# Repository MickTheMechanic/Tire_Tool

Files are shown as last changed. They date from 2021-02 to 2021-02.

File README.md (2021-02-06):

# Tire Tool
## An open-source datalogging tire pyrometer with built in thermal camera and tire pressure gauge
<br />This work is licensed under a <a rel="license" href="http://creativecommons.org/licenses/by-nc/4.0/">Creative Commons Attribution-NonCommercial 4.0 International License</a>.




The GUI was developed using the [GUI-Slice library](https://github.com/ImpulseAdventure/GUIslice) and [builder](https://github.com/ImpulseAdventure/GUIslice/wiki/GUIslice-Builder). The GUI-Slice project file is included so changed to the GUI can be easily made as needed.

This project is not for the faint hearted, alot of technical knowlage is needed to complete this build. 

# This project is not finished yet, there is no point openening any issues! 
All issues will be ignored until the project is deemed complete, there are alot of changes still to be made!
This repo will be regularly updated, this is currently an unfished project, so keep that in mind if you make a fork.

# About the project
An open source datalogging tire pyrometer with built in thermal camera and tire pressure gauge.
The device is powered by 2 18650 lithium batteries and the brain is an ESP32 microcontroller.
The screen is a 2.8" TFT display with resistive touch.




## The device has 4 main functions:
* A tyre pressure gauge (with pressure release valve)
* A temperature gauge to read tire temps from a K-type thermocouple
* A thermal camera
* A datalogger that saves temperatures to SD card



# Pressure Gauge
* Tire pressure is measured with a Honeywell ABP digital pressure sensor. The sensor is very accurate with a high digital resolution, with information being transferred over the I2C BUS.
* A hose with a tire valve adaptor is connected to the device via a DIN2.7 quick connector.
* There is a pressure release valve inside the device used to adjust pressure, which vents out the rear housing to avoid moisture build up inside the housing.
* Pressure is shown in BAR to the 3rd decimal point, with a maximum tolerance of 0.025%.
* Sensor refresh has been limited to 2Hz.
* There is a hold button, which will hold the measured value on the screen. If hold is enabled the value will remain unless the device is turned off, even if you leave the page to use other functions.



# Temperature gauge
* Tire temperature is measured with a K-type thermocouple probe, of which there are several specifically designed for motorsports.
* The signal from the thermocouple is digitised using an MCP9600 chip and a high resolution digital signal is also sent over the I2C BUS.
* Sensor refresh has also been limited to 2Hz.
* There is a hold button, which will hold the measured value on the screen. If hold is enabled the value will remain unless the device is turned off, even if you leave the page to use other functions.
* Temperature is shown in °c to 2 decimal points, with an accuracy of +/- 2°c depending on various factors.



# Thermal camera
* The thermal camera uses an 8x8 thermal array which is interpolated into a higher resolution image.
* A resolution of 18x15, 36x36, or 63x60 can be selected by the user via the settings menu. The default reslution is 36x36.
* There are 7 color pallets avaliable (Ironbow, Rainbow, RainbowHC, Arctic, White hot, Black hot, and Outdoor alert) which can be selected by the user in the settings menu. Each color pallet contains 433 24bit RGB colors.
* There is a cursor shown on the picture which shows the current temperature in the middle of the screen. The curser can be enabled/disabled in the settings menu.
* The measurement scale can be adjusted in various ways. The min and max temps can be individually adjusted by pressing the number box containing these values then entering the new values on the keypad that pops up. Alternitavely the AUTO button can be pressed which will take an average of all temperatures on screen and set the scale to the average +/- 4°c (default).  The auto scale range can be adjusted in the settings menu from +/- 1°c up to +/- 10°c.
* There is a hold button that will pause the picture from the thermal camera. If you leave the page to use other functions the paused image will be lost.
* There is a track button (road symbol), this button is used to take a reading of the asphalt temperature, which will be saved in the datalogger.




# DataLogger
* The data logger saves temperature readings taken from the tires in 3 steps (inside, middle, and outside). Date, time, ambient temperature, and track (asphalt) temperature will also be stored in each log.
* The defaut order to take measurements is front left first, then anticlockwise, although any wheel can be selected by pressing the desired wheel. However the order in which the measurements of the wheel are taken cannot be changed (inside to outside).
* Each time a temperature is taken the ok button (tick) is pressed to temporarily save the reading. 
* If a mistake is made the cancel button (x) can be pressed to delete the last reading.
* The color of the tires on screen will change to indicate the temperature that has been taken.
* The delta of each tire (green), and the average temperatures of the front, real, left, and right sides of the car (orange) are also calculated and shown on screen.
* The values will remain unless the device is turned off, even if you leave the page to use other functions.
* The delete button (trashcan) will delete all temporarily saved values.
* The save button (floppy disc) will open the file directory.
* When the file directory is open there will be 12 car folders and for each car folder 12 log files. Once a folder and file has been selected, the log can be saved by pressing the save button. A green progress bar will indicate the file has been succesfully saved.
* On the same page logs can be loaded, the folder and log file are selected and load is pressed. Once again a green progress bar will indicate success.
* Log files are saved on SD in .txt format, whaich can be easily accessed on any computer.





# Screensaver
* If the device is not used for a period of 2 minutes or more a screen saver will be enabled. It is a black screen with date and time.
* To exit the screen saver simply press any button or touch the touch screen.



# Header
* The header is shown on every page and contains ambient temperature, the track (asphalt) temperature, the date, and time.

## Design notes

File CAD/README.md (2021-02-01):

Cad files for the housing are included in stl form.
The fusion360 project file is also included allowing easy modification.

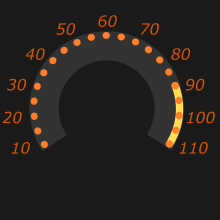
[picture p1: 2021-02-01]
Code/RES/TempGaugeV1_220x220.bmp

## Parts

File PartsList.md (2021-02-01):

## Parts list for the tire tool:
* ESP32 Uno board
* 2.8" tft LCD touch screen (MCUFriends style)
* AMG8833 thermal array breakout
* CJMCU-96 thermocouple breakout
* DS1307 I2C real time clock module
* Honeywell ABPMANV060PG2A3 pressure sensor
* DIYMore V8 18650 battery module
* Cablecc Micro SD TF Memory CardMale to Female Extension Adapter
* Micro SD card
* TAC4V press button valve
* M5 4mm Barbed fitting
* M5 2mm Barbed fitting
* M5 T-piece
* M5 blanking screw
* M5 pneumatic muffler
* DIN2.7 male bulkhead fitting 4mm barb
* DIN2.7 Female connector 6mm barb
* Hose in various sizes (2mm ID, 4mm ID, 6mm ID)
* Dupont connectors and some cable

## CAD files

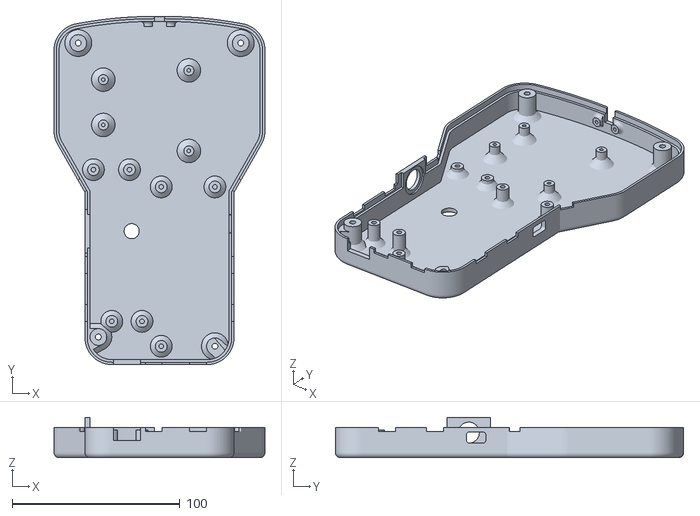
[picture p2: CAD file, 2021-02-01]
CAD/Cover_Back.stl
125.8 x 207.6 x 24.0

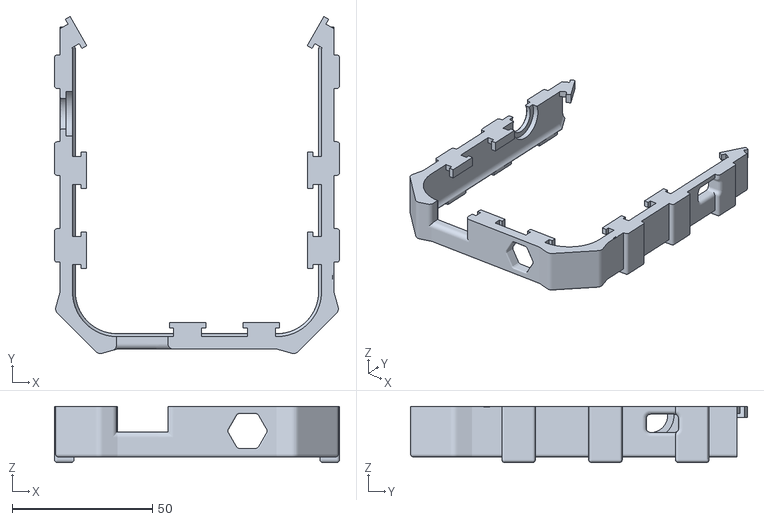
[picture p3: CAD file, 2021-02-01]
CAD/Rubber bottom.stl
101.8 x 120.3 x 20.0

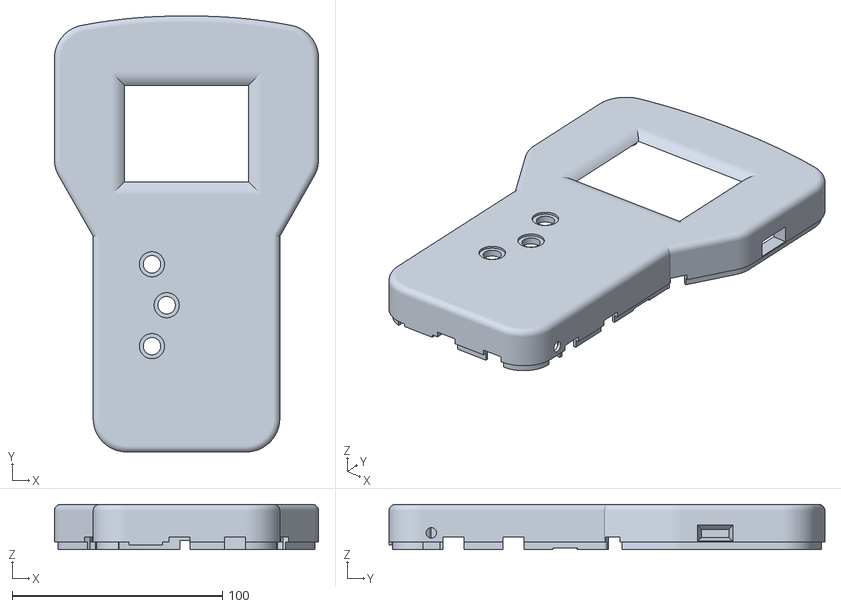
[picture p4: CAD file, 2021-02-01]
CAD/Cover_Front.stl
125.8 x 207.6 x 21.5

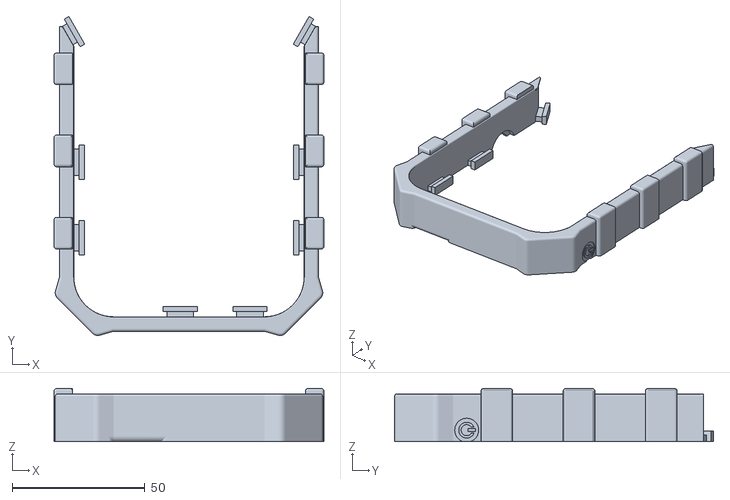
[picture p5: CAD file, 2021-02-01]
CAD/Rubber Top.stl
101.8 x 120.3 x 20.0

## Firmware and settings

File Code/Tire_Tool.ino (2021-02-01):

//<App !Start!>
// FILE: [TireToolFinal.ino]
// Created by GUIslice Builder version: [0.16.b004]
//
// GUIslice Builder Generated File
//
// For the latest guides, updates and support view:
// https://github.com/ImpulseAdventure/GUIslice
//
//<App !End!>

// ------------------------------------------------
// Headers to include
// ------------------------------------------------
#include "TireToolFinal_GSLC.h"
#include "SD.h"
#include "Adafruit_AMG88xx.h"
Adafruit_AMG88xx amg;
#include "RTClib.h"
RTC_DS1307 rtc;
#include "SparkFun_MCP9600.h"
MCP9600 probe;
#include "Honeywell_ABP.h"
Honeywell_ABP abp(0x28,0,60,"psi");


// ------------------------------------------------
// Program Globals
// ------------------------------------------------
bool pauseTemp = false;
bool pausePressure = false;
unsigned long screensaverTimer;
unsigned long refreshTimer;
unsigned long currentMillis;
const uint16_t Minutes = 60000;
const uint8_t Halfseconds = 500;
uint8_t lastPageId = PG_Home;

// ------------------------------------------------
// Temperature Probe Globals
// ------------------------------------------------
char  tempBuf [8];
int16_t gaugeVal;
float   probeTemp;


// ------------------------------------------------
// Pressure Gauge Globals
// ------------------------------------------------
char  pressureBuf [8];
float    gaugePressure;
float    sensorPressure;


// ------------------------------------------------
// Data Log Globals
// ------------------------------------------------
char   logTemp[5];
char   logFolder[MAX_STR];
char   logName[MAX_STR];
char   logPath[MAX_STR];
char   LogInfoBuf [MAX_STR];
char   averageBuf [7];
char   deltaBuf [MAX_STR];
char   trackTempBuf [MAX_STR];
char   ambTempBuf [MAX_STR];
const char* dateBuf;
static char nullnullval[7] = "---.--";
const uint8_t   Left = 0;
const uint8_t   Rear = 1;
const uint8_t   Right = 2;
const uint8_t   Front = 3;
const uint8_t   FrontLeft = 0;
const uint8_t   RearLeft = 1;
const uint8_t   RearRight = 2;
const uint8_t   FrontRight = 3;
const uint8_t   numberLogLines (15);
int8_t  ambTemp;
int8_t  counter = -1;
int16_t  dataFieldInt [12];
int16_t  cornerAverage [4];
int16_t  cornerHighTemp[4];
int16_t  cornerLowTemp[4];
float  cornerDelta [4];
float  sideAverage [4];


// ------------------------------------------------
// Thermal Camera Globals
// ------------------------------------------------
#define AMG_COLS 8
#define AMG_ROWS 8
bool pauseThermal = false;
bool autoScale = false;
bool cursorOn = true;
bool DefaultTemp = true;
char  scaleRangeBuf[3];
char  minTempBuf [3];
char  maxTempBuf [3];
char  cursorTempBuf [5];
int8_t  MINTEMP = 20;
int8_t  MAXTEMP = 30;
uint8_t  thermalCol;
uint8_t  thermalSel;
uint8_t  scaleRange = 4;
uint8_t  INTERPOLATED_COLS = 36;
uint8_t  INTERPOLATED_ROWS = 36;
uint8_t  boxWidth = 7;
uint8_t  boxHeight = 5;
uint8_t  red, green, blue;
uint16_t   colorMap;
float  colorTemp;
float  cursorTemp;
float  pixels[AMG_COLS * AMG_ROWS];
float  dest_2d[3780]; //array size must match the largest number of rows * columns that can be encountered during runtime
float  get_point(float *p, uint8_t rows, uint8_t cols, int8_t x, int8_t y);
float  cubicInterpolate(float p[], float x);
float  bicubicInterpolate(float p[], float x, float y);
void set_point(float *p, uint8_t rows, uint8_t cols, int8_t x, int8_t y, float f);
void get_adjacents_1d(float *src, float *dest, uint8_t rows, uint8_t cols, int8_t x, int8_t y);
void get_adjacents_2d(float *src, float *dest, uint8_t rows, uint8_t cols, int8_t x, int8_t y);
void interpolate_image(float *src, uint8_t src_rows, uint8_t src_cols, float *dest, uint8_t dest_rows, uint8_t dest_cols);



const uint32_t colorPallete [][433] = {

  //IRONBOW
  { 0x00000a, 0x000014, 0x00001e, 0x000025, 0x00002a, 0x00002e, 0x000032, 0x000036, 0x00003a, 0x00003e, 0x000042,
    0x000046, 0x00004a, 0x00004f, 0x000052, 0x010055, 0x010057, 0x020059, 0x02005c, 0x03005e, 0x040061, 0x040063,
    0x050065, 0x060067, 0x070069, 0x08006b, 0x09006e, 0x0a0070, 0x0b0073, 0x0c0074, 0x0d0075, 0x0d0076, 0x0e0077,
    0x100078, 0x120079, 0x13007b, 0x15007c, 0x17007d, 0x19007e, 0x1b0080, 0x1c0081, 0x1e0083, 0x200084, 0x220085,
    0x240086, 0x260087, 0x280089, 0x2a0089, 0x2c008a, 0x2e008b, 0x30008c, 0x32008d, 0x34008e, 0x36008e, 0x38008f,
    0x390090, 0x3b0091, 0x3c0092, 0x3e0093, 0x3f0093, 0x410094, 0x420095, 0x440095, 0x450096, 0x470096, 0x490096,
    0x4a0096, 0x4c0097, 0x4e0097, 0x4f0097, 0x510097, 0x520098, 0x540098, 0x560098, 0x580099, 0x5a0099, 0x5c0099,
    0x5d009a, 0x5f009a, 0x61009b, 0x63009b, 0x64009b, 0x66009b, 0x68009b, 0x6a009b, 0x6c009c, 0x6d009c, 0x6f009c,
    0x70009c, 0x71009d, 0x73009d, 0x75009d, 0x77009d, 0x78009d, 0x7a009d, 0x7c009d, 0x7e009d, 0x7f009d, 0x81009d,
    0x83009d, 0x84009d, 0x86009d, 0x87009d, 0x89009d, 0x8a009d, 0x8b009d, 0x8d009d, 0x8f009c, 0x91009c, 0x93009c,
    0x95009c, 0x96009b, 0x98009b, 0x99009b, 0x9b009b, 0x9c009b, 0x9d009b, 0x9f009b, 0xa0009b, 0xa2009b, 0xa3009b,
    0xa4009b, 0xa6009a, 0xa7009a, 0xa8009a, 0xa90099, 0xaa0099, 0xab0099, 0xad0099, 0xae0198, 0xaf0198, 0xb00198,
    0xb00198, 0xb10197, 0xb20197, 0xb30196, 0xb40296, 0xb50295, 0xb60295, 0xb70395, 0xb80395, 0xb90495, 0xba0495,
    0xba0494, 0xbb0593, 0xbc0593, 0xbd0593, 0xbe0692, 0xbf0692, 0xbf0692, 0xc00791, 0xc00791, 0xc10890, 0xc10990,
    0xc20a8f, 0xc30a8e, 0xc30b8e, 0xc40c8d, 0xc50c8c, 0xc60d8b, 0xc60e8a, 0xc70f89, 0xc81088, 0xc91187, 0xca1286,
    0xca1385, 0xcb1385, 0xcb1484, 0xcc1582, 0xcd1681, 0xce1780, 0xce187e, 0xcf187c, 0xcf197b, 0xd01a79, 0xd11b78,
    0xd11c76, 0xd21c75, 0xd21d74, 0xd31e72, 0xd32071, 0xd4216f, 0xd4226e, 0xd5236b, 0xd52469, 0xd62567, 0xd72665,
    0xd82764, 0xd82862, 0xd92a60, 0xda2b5e, 0xda2c5c, 0xdb2e5a, 0xdb2f57, 0xdc2f54, 0xdd3051, 0xdd314e, 0xde324a,
    0xde3347, 0xdf3444, 0xdf3541, 0xdf363d, 0xe0373a, 0xe03837, 0xe03933, 0xe13a30, 0xe23b2d, 0xe23c2a, 0xe33d26,
    0xe33e23, 0xe43f20, 0xe4411d, 0xe4421c, 0xe5431b, 0xe54419, 0xe54518, 0xe64616, 0xe74715, 0xe74814, 0xe74913,
    0xe84a12, 0xe84c10, 0xe84c0f, 0xe94d0e, 0xe94d0d, 0xea4e0c, 0xea4f0c, 0xeb500b, 0xeb510a, 0xeb520a, 0xeb5309,
    0xec5409, 0xec5608, 0xec5708, 0xec5808, 0xed5907, 0xed5a07, 0xed5b06, 0xee5c06, 0xee5c05, 0xee5d05, 0xee5e05,
    0xef5f04, 0xef6004, 0xef6104, 0xef6204, 0xf06303, 0xf06403, 0xf06503, 0xf16603, 0xf16603, 0xf16703, 0xf16803,
    0xf16902, 0xf16a02, 0xf16b02, 0xf16b02, 0xf26c01, 0xf26d01, 0xf26e01, 0xf36f01, 0xf37001, 0xf37101, 0xf37201,
    0xf47300, 0xf47400, 0xf47500, 0xf47600, 0xf47700, 0xf47800, 0xf47a00, 0xf57b00, 0xf57c00, 0xf57e00, 0xf57f00,
    0xf68000, 0xf68100, 0xf68200, 0xf78300, 0xf78400, 0xf78500, 0xf78600, 0xf88700, 0xf88800, 0xf88800, 0xf88900,
    0xf88a00, 0xf88b00, 0xf88c00, 0xf98d00, 0xf98d00, 0xf98e00, 0xf98f00, 0xf99000, 0xf99100, 0xf99200, 0xf99300,
    0xfa9400, 0xfa9500, 0xfa9600, 0xfb9800, 0xfb9900, 0xfb9a00, 0xfb9c00, 0xfc9d00, 0xfc9f00, 0xfca000, 0xfca100,
    0xfda200, 0xfda300, 0xfda400, 0xfda600, 0xfda700, 0xfda800, 0xfdaa00, 0xfdab00, 0xfdac00, 0xfdad00, 0xfdae00,
    0xfeaf00, 0xfeb000, 0xfeb100, 0xfeb200, 0xfeb300, 0xfeb400, 0xfeb500, 0xfeb600, 0xfeb800, 0xfeb900, 0xfeb900,
    0xfeba00, 0xfebb00, 0xfebc00, 0xfebd00, 0xfebe00, 0xfec000, 0xfec100, 0xfec200, 0xfec300, 0xfec400, 0xfec500,
    0xfec600, 0xfec700, 0xfec800, 0xfec901, 0xfeca01, 0xfeca01, 0xfecb01, 0xfecc02, 0xfecd02, 0xfece03, 0xfecf04,
    0xfecf04, 0xfed005, 0xfed106, 0xfed308, 0xfed409, 0xfed50a, 0xfed60a, 0xfed70b, 0xfed80c, 0xfed90d, 0xffda0e,
    0xffda0e, 0xffdb10, 0xffdc12, 0xffdc14, 0xffdd16, 0xffde19, 0xffde1b, 0xffdf1e, 0xffe020, 0xffe122, 0xffe224,
    0xffe226, 0xffe328, 0xffe42b, 0xffe42e, 0xffe531, 0xffe635, 0xffe638, 0xffe73c, 0xffe83f, 0xffe943, 0xffea46,
    0xffeb49, 0xffeb4d, 0xffec50, 0xffed54, 0xffee57, 0xffee5b, 0xffee5f, 0xffef63, 0xffef67, 0xfff06a, 0xfff06e,
    0xfff172, 0xfff177, 0xfff17b, 0xfff280, 0xfff285, 0xfff28a, 0xfff38e, 0xfff492, 0xfff496, 0xfff49a, 0xfff59e,
    0xfff5a2, 0xfff5a6, 0xfff6aa, 0xfff6af, 0xfff7b3, 0xfff7b6, 0xfff8ba, 0xfff8bd, 0xfff8c1, 0xfff8c4, 0xfff9c7,
    0xfff9ca, 0xfff9cd, 0xfffad1, 0xfffad4, 0xfffbd8, 0xfffcdb, 0xfffcdf, 0xfffde2, 0xfffde5, 0xfffde8, 0xfffeeb,
    0xfffeee, 0xfffef1, 0xfffef4, 0xfffff6,
  },

  //RAINBOW
  { 0xFF, 0x2FF, 0x5FF, 0x8FF, 0xBFF, 0xEFF, 0x11FF, 0x14FF, 0x17FF, 0x1AFF, 0x1DFF,
    0x20FF, 0x23FF, 0x26FF, 0x29FF, 0x2CFF, 0x2FFF, 0x32FF, 0x35FF, 0x37FF, 0x3AFF, 0x3DFF,
    0x40FF, 0x43FF, 0x46FF, 0x49FF, 0x4CFF, 0x4FFF, 0x52FF, 0x55FF, 0x58FF, 0x5BFF, 0x5EFF,
    0x61FF, 0x64FF, 0x67FF, 0x6AFF, 0x6CFF, 0x6FFF, 0x72FF, 0x75FF, 0x78FF, 0x7BFF, 0x7EFF,
    0x81FF, 0x84FF, 0x87FF, 0x8AFF, 0x8DFF, 0x90FF, 0x93FF, 0x96FF, 0x99FF, 0x9CFF, 0x9FFF,
    0xA1FF, 0xA4FF, 0xA7FF, 0xAAFF, 0xADFF, 0xB0FF, 0xB3FF, 0xB6FF, 0xB9FF, 0xBCFF, 0xBFFF,
    0xC2FF, 0xC5FF, 0xC8FF, 0xCBFF, 0xCEFF, 0xD1FF, 0xD4FF, 0xD6FF, 0xD9FF, 0xDCFF, 0xDFFF,
    0xE2FF, 0xE5FF, 0xE8FF, 0xEBFF, 0xEEFF, 0xF1FF, 0xF4FF, 0xF7FF, 0xFAFF, 0xFDFF, 0xFFFD,
    0xFFFA, 0xFFF7, 0xFFF4, 0xFFF2, 0xFFEF, 0xFFEC, 0xFFE9, 0xFFE6, 0xFFE3, 0xFFE0, 0xFFDD,
    0xFFDA, 0xFFD7, 0xFFD4, 0xFFD1, 0xFFCE, 0xFFCB, 0xFFC8, 0xFFC5, 0xFFC2, 0xFFBF, 0xFFBD,
    0xFFBA, 0xFFB7, 0xFFB4, 0xFFB1, 0xFFAE, 0xFFAB, 0xFFA8, 0xFFA5, 0xFFA2, 0xFF9F, 0xFF9C,
    0xFF99, 0xFF96, 0xFF93, 0xFF90, 0xFF8D, 0xFF8A, 0xFF88, 0xFF85, 0xFF82, 0xFF7F, 0xFF7C,
    0xFF79, 0xFF76, 0xFF73, 0xFF70, 0xFF6D, 0xFF6A, 0xFF67, 0xFF64, 0xFF61, 0xFF5E, 0xFF5B,
    0xFF58, 0xFF55, 0xFF53, 0xFF50, 0xFF4D, 0xFF4A, 0xFF47, 0xFF44, 0xFF41, 0xFF3E, 0xFF3B,
    0xFF38, 0xFF35, 0xFF32, 0xFF2F, 0xFF2C, 0xFF29, 0xFF26, 0xFF23, 0xFF20, 0xFF1E, 0xFF1B,
    0xFF18, 0xFF15, 0xFF12, 0xFF0F, 0xFF0C, 0xFF09, 0xFF06, 0xFF03, 0xFF00, 0x2FF00, 0x5FF00,
    0x8FF00, 0xBFF00, 0xEFF00, 0x11FF00, 0x14FF00, 0x16FF00, 0x19FF00, 0x1CFF00, 0x1FFF00, 0x22FF00, 0x25FF00,
    0x28FF00, 0x2BFF00, 0x2EFF00, 0x31FF00, 0x34FF00, 0x37FF00, 0x3AFF00, 0x3DFF00, 0x40FF00, 0x43FF00, 0x46FF00,
    0x49FF00, 0x4BFF00, 0x4EFF00, 0x51FF00, 0x54FF00, 0x57FF00, 0x5AFF00, 0x5DFF00, 0x60FF00, 0x63FF00, 0x66FF00,
    0x69FF00, 0x6CFF00, 0x6FFF00, 0x72FF00, 0x75FF00, 0x78FF00, 0x7BFF00, 0x7EFF00, 0x80FF00, 0x83FF00, 0x86FF00,
    0x89FF00, 0x8CFF00, 0x8FFF00, 0x92FF00, 0x95FF00, 0x98FF00, 0x9BFF00, 0x9EFF00, 0xA1FF00, 0xA4FF00, 0xA7FF00,
    0xAAFF00, 0xADFF00, 0xB0FF00, 0xB3FF00, 0xB5FF00, 0xB8FF00, 0xBBFF00, 0xBEFF00, 0xC1FF00, 0xC4FF00, 0xC7FF00,
    0xCAFF00, 0xCDFF00, 0xD0FF00, 0xD3FF00, 0xD6FF00, 0xD9FF00, 0xDCFF00, 0xDFFF00, 0xE2FF00, 0xE5FF00, 0xE8FF00,
    0xEAFF00, 0xEDFF00, 0xF0FF00, 0xF3FF00, 0xF6FF00, 0xF9FF00, 0xFCFF00, 0xFFFE00, 0xFFFB00, 0xFFF800, 0xFFF500,
    0xFFF200, 0xFFEF00, 0xFFEC00, 0xFFE900, 0xFFE600, 0xFFE300, 0xFFE000, 0xFFDE00, 0xFFDB00, 0xFFD800, 0xFFD500,
    0xFFD200, 0xFFCF00, 0xFFCC00, 0xFFC900, 0xFFC600, 0xFFC300, 0xFFC000, 0xFFBD00, 0xFFBA00, 0xFFB700, 0xFFB400,
    0xFFB100, 0xFFAE00, 0xFFAB00, 0xFFA900, 0xFFA600, 0xFFA300, 0xFFA000, 0xFF9D00, 0xFF9A00, 0xFF9700, 0xFF9400,
    0xFF9100, 0xFF8E00, 0xFF8B00, 0xFF8800, 0xFF8500, 0xFF8200, 0xFF7F00, 0xFF7C00, 0xFF7900, 0xFF7600, 0xFF7400,
    0xFF7100, 0xFF6E00, 0xFF6B00, 0xFF6800, 0xFF6500, 0xFF6200, 0xFF5F00, 0xFF5C00, 0xFF5900, 0xFF5600, 0xFF5300,
    0xFF5000, 0xFF4D00, 0xFF4A00, 0xFF4700, 0xFF4400, 0xFF4100, 0xFF3F00, 0xFF3C00, 0xFF3900, 0xFF3600, 0xFF3300,
    0xFF3000, 0xFF2D00, 0xFF2A00, 0xFF2700, 0xFF2400, 0xFF2100, 0xFF1E00, 0xFF1B00, 0xFF1800, 0xFF1500, 0xFF1200,
    0xFF0F00, 0xFF0C00, 0xFF0A00, 0xFF0700, 0xFF0400, 0xFF0100, 0xFF0001, 0xFF0004, 0xFF0007, 0xFF0009, 0xFF000C,
    0xFF000F, 0xFF0012, 0xFF0015, 0xFF0017, 0xFF001A, 0xFF001D, 0xFF0020, 0xFF0022, 0xFF0025, 0xFF0028, 0xFF002B,
    0xFF002E, 0xFF0030, 0xFF0033, 0xFF0036, 0xFF0039, 0xFF003B, 0xFF003E, 0xFF0041, 0xFF0044, 0xFF0046, 0xFF0049,
    0xFF004C, 0xFF004F, 0xFF0052, 0xFF0054, 0xFF0057, 0xFF005A, 0xFF005D, 0xFF005F, 0xFF0062, 0xFF0065, 0xFF0068,
    0xFF006A, 0xFF006D, 0xFF0070, 0xFF0073, 0xFF0076, 0xFF0078, 0xFF007B, 0xFF007E, 0xFF0081, 0xFF0083, 0xFF0086,
    0xFF0089, 0xFF008C, 0xFF008F, 0xFF0091, 0xFF0094, 0xFF0097, 0xFF009A, 0xFF009C, 0xFF009F, 0xFF00A2, 0xFF00A5,
    0xFF00A7, 0xFF00AA, 0xFF00AD, 0xFF00B0, 0xFF00B3, 0xFF00B5, 0xFF00B8, 0xFF00BB, 0xFF00BE, 0xFF00C0, 0xFF00C3,
    0xFF00C6, 0xFF00C9, 0xFF00CB, 0xFF00CE, 0xFF00D1, 0xFF00D4, 0xFF00D7, 0xFF00D9, 0xFF00DC, 0xFF00DF, 0xFF00E2,
    0xFF00E4, 0xFF00E7, 0xFF00EA, 0xFF00ED,
  },
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
void loop()
{
  // ------------------------------------------------
  // General
  // ------------------------------------------------
  
  currentMillis = millis();
  DateTime now = rtc.now();

  // ------------------------------------------------
  // Update Base Page Headers
  // ------------------------------------------------


  if (gslc_GetPageCur(&m_gui) == PG_ScreenSaver) {
    char Time [] = "hh:mm";
    gslc_ElemSetTxtStr(&m_gui, timeTxt, (now.toString(Time)));
    char Date [] = "DDD, DD/MM/YYYY";
    gslc_ElemSetTxtStr(&m_gui, dateTxt, (now.toString(Date)));
  }
  else {
    ambTemp = amg.readThermistor();
    if (ambTemp != -127) {
      snprintf(ambTempBuf, MAX_STR, "Amb Temp:%d'C", ambTemp);
      gslc_ElemSetTxtStr(&m_gui, ambTempTxt, ambTempBuf);
    }
    char dateTime[] = "DDD, DD/MM/YYYY hh:mm";
    gslc_ElemSetTxtStr(&m_gui, dateTimeTxt, (now.toString(dateTime)));
    if (currentMillis - screensaverTimer >= 1 * Minutes) {
      lastPageId = gslc_GetPageCur(&m_gui) ;
      gslc_PopupHide(&m_gui);
      gslc_SetPageCur(&m_gui, PG_ScreenSaver);
    }
  }


  // ------------------------------------------------
  // Update GUI Elements
  // ------------------------------------------------

  if (gslc_GetPageCur(&m_gui) == PG_Pressure && pausePressure == false) {
    if (currentMillis - refreshTimer >= 1 * Halfseconds) {
      GetPressure();
      snprintf(pressureBuf, MAX_STR, "%.3f", gaugePressure);
      gslc_ElemSetTxtStr(&m_gui, pressGauge, pressureBuf);
      gslc_ElemXRingGaugeSetVal(&m_gui, pressGauge, gaugeVal);
      refreshTimer = currentMillis;
    }
  }

   if (gslc_GetPageCur(&m_gui) == PG_Temp && pauseTemp == false) {
    if (currentMillis - refreshTimer >= 1 * Halfseconds) {
      GetTemperature();
      snprintf(tempBuf, MAX_STR, "%.2f'C", probeTemp);
      gslc_ElemSetTxtStr(&m_gui, tempGauge, tempBuf);
      gslc_ElemXRingGaugeSetVal(&m_gui, tempGauge, gaugeVal);
      refreshTimer = currentMillis;
    }
  }


  if (gslc_GetPageCur(&m_gui) == PG_Log) {
    if (isnan(probeTemp)) {
      if ((gslc_ElemGetVisible(&m_gui, logTempTxt) == true)) {
        gslc_ElemSetVisible(&m_gui, logTempTxt, false);
      }
    }
    else {
      if (gslc_ElemGetVisible(&m_gui, logTempTxt) == false) {
        gslc_ElemSetVisible(&m_gui, logTempTxt, true);
      }
      if (currentMillis - refreshTimer >= 1 * Halfseconds) {
        GetTemperature();
        snprintf(tempBuf, MAX_STR, "%.2f'C", probeTemp);
        gslc_ElemSetTxtStr(&m_gui, logTempTxt, tempBuf);
        refreshTimer = currentMillis;
      }
    }
  }



  if (gslc_GetPageCur(&m_gui) == PG_Thermal && pauseThermal == false) {
      amg.readPixels(pixels);
      interpolate_image(pixels, AMG_ROWS, AMG_COLS, dest_2d, INTERPOLATED_ROWS, INTERPOLATED_COLS);
      drawpixels(dest_2d, INTERPOLATED_ROWS, INTERPOLATED_COLS, boxWidth, boxHeight, false);
  }


  // ------------------------------------------------
  // Periodically call GUIslice update function
  // ------------------------------------------------
  gslc_Update(&m_gui);

}


// ----------------------------------------------------------------------------------------------------
// Thermal Camera Functions
// ----------------------------------------------------------------------------------------------------
void drawpixels(float * p, uint8_t rows, uint8_t cols, uint8_t boxWidth, uint8_t boxHeight, boolean showVal) { //From Adafruit example
  for (int y = 0; y < rows; y++) {
    for (int x = 0; x < cols; x++) {
      float val = get_point(p, rows, cols, x, y);
      if (val >= MAXTEMP) colorTemp = MAXTEMP;
      else if (val <= MINTEMP) colorTemp = MINTEMP;
      else colorTemp = val;
      uint16_t colorIndex = map(colorTemp * 1000, MINTEMP * 1000, MAXTEMP * 1000, 0, 432);
      colorIndex = constrain(colorIndex, 0, 432);
      gslc_tsRect rCamRect = {
        60 + boxWidth * x,
        20 + boxHeight * y,
        boxWidth,
        boxHeight
      };
      uint32_t     nCamColor_HEX = colorPallete [thermalCol] [colorIndex];
      gslc_tsColor nCamCol_rgb;
      nCamCol_rgb.r = ((nCamColor_HEX >> 16) & 0xFF);
      nCamCol_rgb.g = ((nCamColor_HEX >> 8) & 0xFF);
      nCamCol_rgb.b = ((nCamColor_HEX) & 0xFF) ;
      gslc_DrvDrawFillRect(&m_gui, rCamRect, nCamCol_rgb);
    }
    if (cursorOn == true) {
      SetCursor ();
    }
  }
  if (autoScale == true) {
    SetTempScale();
  }

}

void SetTempScale() {
  if (DefaultTemp == true) {
    MINTEMP = 20;
    MAXTEMP = 30;
  }
  else {
    float val = 0.0;
    for (int i = 0; i < 64; i++) {
      val = val + pixels[i];
    }
    val = val / 64.0;
    MINTEMP = val - scaleRange;
    MAXTEMP = val + scaleRange;
    snprintf(minTempBuf, 3, "%d", MINTEMP);
    gslc_ElemSetTxtStr(&m_gui, minTempBtn  , minTempBuf);
    snprintf(maxTempBuf, 3, "%d", MAXTEMP);
    gslc_ElemSetTxtStr(&m_gui, maxTempBtn, maxTempBuf);
  }
}

void SetColorPreview (int preview_x, int preview_y, int preview_h, int pallete ) {
  if ((pallete < 0) | (pallete > 6) ) {
    for (int j = 0; j < 150; j++) {
      gslc_DrawLineV (&m_gui, preview_x + j, preview_y, preview_h, GSLC_COL_WHITE);
    }
  }
  else {
    for (int j = 0; j < 150; j++) {
      colorMap = map (j, 0, 150, 0, 432);
      uint32_t     nColorMap_HEX = colorPallete [pallete] [colorMap];
      gslc_tsColor nColorMap_rgb;
      nColorMap_rgb.r = ((nColorMap_HEX >> 16) & 0xFF);
      nColorMap_rgb.g = ((nColorMap_HEX >> 8) & 0xFF);
      nColorMap_rgb.b = ((nColorMap_HEX) & 0xFF) ;
      gslc_DrawLineV (&m_gui, preview_x + j, preview_y, preview_h, nColorMap_rgb);
    }
  }
}

void SetResolution (int resolution) {
  if (resolution == 0) {      //Low Resolution
    gslc_ElemSetTxtStr(&m_gui, resTxt , "Low");
    INTERPOLATED_COLS = 18;
    INTERPOLATED_ROWS = 15;
    boxWidth = 14;
    boxHeight = 12;
  }
  else if (resolution == 1) { //Medium Resolution
    gslc_ElemSetTxtStr(&m_gui, resTxt , "Medium");
    INTERPOLATED_COLS = 36;
    INTERPOLATED_ROWS = 36;
    boxWidth = 7;
    boxHeight = 5;
  }
  else if (resolution == 2) { //High Resolution
    gslc_ElemSetTxtStr(&m_gui, resTxt , "High");
    INTERPOLATED_COLS = 63;
    INTERPOLATED_ROWS = 60;
    boxWidth =  4;
    boxHeight = 3;
  }
}

void SetCursor () {
  cursorTemp = (pixels [28] + pixels [29] + pixels [36] + pixels [37]) / 4;
  snprintf(cursorTempBuf, 7, "%.2f", cursorTemp);
  for (int j = 0; j < 3; j++) {
    gslc_DrawLineH (&m_gui, 171, 109 + j, 30, GSLC_COL_WHITE);
    gslc_DrawLineV (&m_gui, 185 + j, 95, 30, GSLC_COL_WHITE);
  }
  gslc_ElemSetTxtStr(&m_gui, cursorTxt , cursorTempBuf);
}



// ---------------------------------------------------------------------------------------
// Data Log Functions
// ---------------------------------------------------------------------------------------
void GetTireColor (uint8_t wheelPos, int16_t outside, int16_t middle, int16_t inside) {
  unsigned int tireColor;
  int tire_x;
  int tire_y;
  int i = 4;
  int n = 4;
  int insideTempCol = map (constrain (inside / 100, 15, 120), 15, 120, 0, 432);
  int middleTempCol = map (constrain (middle / 100, 15, 120), 15, 120, 0, 432);
  int outsideTempCol = map (constrain (outside / 100, 15, 120), 15, 120, 0, 432);
  switch (wheelPos) {
    case FrontLeft:
      tire_x = 120;
      tire_y = 40;
      break;
    case RearLeft:
      tire_x = 120;
      tire_y = 170;
      break;
    case RearRight:
      tire_x = 220;
      tire_y = 170;
      break;
    case FrontRight:
      tire_x = 220;
      tire_y = 40;
      break;
  }
  for (int j = 0; j < 30; j++) {
    if (j <= 5) {
      tireColor = outsideTempCol;
    }
    else if ((j >= 6) & (j <= 11)) {
      tireColor = outsideTempCol + ((middleTempCol - outsideTempCol) / 6) * (j - 6) ;
    }
    else if ((j >= 12) & (j <= 17)) {
      tireColor = middleTempCol;
    }
    else if ((j >= 18) & (j <= 23)) {
      tireColor = middleTempCol + ((insideTempCol - middleTempCol) / 6) * (j - 17) ;
    }
    else if (j >= 24) {
      tireColor = insideTempCol;
    }
    uint32_t nTireColor_HEX = colorPallete [1] [tireColor];
    gslc_tsColor nTireColor_rgb;
    nTireColor_rgb.r = ((nTireColor_HEX >> 16) & 0xFF);
    nTireColor_rgb.g = ((nTireColor_HEX >> 8) & 0xFF);
    nTireColor_rgb.b = ((nTireColor_HEX) & 0xFF) ;
    gslc_DrawLineV (&m_gui, tire_x + j , tire_y + i , 50 - (i * 2), nTireColor_rgb);
    if (j < 4) {
      i --;
    }
    else if (j >= 25) {
      i++;
    }
  }
}

void SetTireColor() {
  gslc_tsElemRef* Tire[] = {
    frontLeft,
    frontRight,
    rearLeft,
    rearRight,
  };
  for (uint8_t i = 0; i < 4; i++) {
    gslc_ElemSetRedraw(&m_gui, Tire[i], GSLC_REDRAW_FULL);
  }
}
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

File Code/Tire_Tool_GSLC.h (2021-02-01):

//<File !Start!>
// FILE: [TireToolFinal_GSLC.h]
// Created by GUIslice Builder version: [0.16.b004]
//
// GUIslice Builder Generated GUI Framework File
//
// For the latest guides, updates and support view:
// https://github.com/ImpulseAdventure/GUIslice
//
//<File !End!>

#ifndef _GUISLICE_GEN_H
#define _GUISLICE_GEN_H

// ------------------------------------------------
// Headers to include
// ------------------------------------------------
#include "GUIslice.h"
#include "GUIslice_drv.h"

// Include any extended elements
//<Includes !Start!>
// Include extended elements
#include "elem/XKeyPad_Num.h"
#include "elem/XListbox.h"
#include "elem/XProgress.h"
#include "elem/XRingGauge.h"
#include "elem/XSlider.h"
#include "elem/XTogglebtn.h"

// Ensure optional features are enabled in the configuration
#if !(GSLC_SD_EN)
  #error "Config: GSLC_SD_EN required for this program but not enabled. Please see: https://github.com/ImpulseAdventure/GUIslice/wiki/Configuring-GUIslice"
#endif
//<Includes !End!>

// ------------------------------------------------
// Headers and Defines for fonts
// Note that font files are located within the Adafruit-GFX library folder:
// ------------------------------------------------
//<Fonts !Start!>
#if defined(DRV_DISP_TFT_ESPI)
  #error Project tab->Target Platform should be tft_espi
#endif
#include <Adafruit_GFX.h>
#include "Fonts/FreeSans24pt7b.h"
#include "Fonts/FreeSans9pt7b.h"
#include "Fonts/FreeSansBoldOblique12pt7b.h"
#include "Fonts/FreeSansBoldOblique9pt7b.h"
#include "Fonts/NotoSans8pt7b.h"
#include "Fonts/dosis_bold14pt7b.h"
#include "Fonts/dosis_book8pt7b.h"
//<Fonts !End!>

// ------------------------------------------------
// Defines for resources
// ------------------------------------------------
//<Resources !Start!>
#define IMG_BACKGROUNDV2          "/backgroundV2.bmp"
#define IMG_BACKSPACE             "/backspace.bmp"
#define IMG_GAUGEV3_220X220       "/GaugeV3_220x220.bmp"
#define IMG_HOMEINACTIVE          "/HomeInactive.bmp"
#define IMG_LOG                   "/log.bmp"
#define IMG_OK                    "/OK.bmp"
#define IMG_PRESS                 "/press.bmp"
#define IMG_SAVE                  "/save.bmp"
#define IMG_SETTINGS              "/settings.bmp"
#define IMG_TEMP                  "/temp.bmp"
#define IMG_TEMPGAUGEV1_220X220   "/TempGaugeV1_220x220.bmp"
#define IMG_THERMAL               "/thermal.bmp"
#define IMG_TRACK                 "/track.bmp"
#define IMG_TRASH                 "/trash.bmp"
//<Resources !End!>

// ------------------------------------------------
// Enumerations for pages, elements, fonts, images
// ------------------------------------------------
//<Enum !Start!>
enum {E_PG_BASE,PG_ScreenSaver,PG_Home,PG_Pressure,PG_Temp,PG_Thermal
      ,PG_Log,THERMAL_SETTINGS,LOG_SAVE_LOAD,CONFIRM_DELETE
      ,E_POP_KEYPAD_NUM};
enum {AMB_TEMP_TXT,AUTO_BTN,AUTO_SCALE_SCRL,AUTO_SCALE_TXT,AV_FRONT_TXT
      ,AV_LEFT_TXT,AV_REAR_TXT,AV_RIGHT_TXT,BACKSPACE_BTN
      ,COLOR_BACK_BTN,COLOR_LIST,COLOR_LIST_SCRL,COLOR_SELECT_BTN
      ,CURSOR_BTN,CURSOR_ON_TXT,CURSOR_TXT,DATA_TXT_1,DATA_TXT_10
      ,DATA_TXT_11,DATA_TXT_12,DATA_TXT_2,DATA_TXT_3,DATA_TXT_4
      ,DATA_TXT_5,DATA_TXT_6,DATA_TXT_7,DATA_TXT_8,DATA_TXT_9
      ,DATE_TIME_TXT,DATE_TXT,DEFAULT_BTN,DELETE_BTN,DELTA_FL_TXT
      ,DELTA_FR_TXT,DELTA_RL_TXT,DELTA_RR_TXT,E_DRAW_LINE1,E_ELEM_BOX10
      ,E_ELEM_BOX11,E_ELEM_BOX12,E_ELEM_BOX17,E_ELEM_BOX2,E_ELEM_BOX7
      ,E_ELEM_IMAGE1,E_ELEM_IMAGE18,E_ELEM_IMAGE2,E_ELEM_TEXT10
      ,E_ELEM_TEXT11,E_ELEM_TEXT35,E_ELEM_TEXT42,E_ELEM_TEXT44
      ,E_ELEM_TEXT45,E_ELEM_TEXT46,E_ELEM_TEXT47,E_ELEM_TEXT48
      ,E_ELEM_TEXT51,E_ELEM_TEXT53,E_ELEM_TEXT56,E_ELEM_TEXT58
      ,E_ELEM_TEXT6,E_ELEM_TEXT60,E_ELEM_TEXT67,E_ELEM_TEXT68
      ,E_ELEM_TEXT7,E_ELEM_TEXT70,E_ELEM_TEXT8,E_ELEM_TEXT9,FRONT_LEFT
      ,FRONT_RIGHT,HOME_BTN,LOG_AMB_TXT,LOG_BACK_BTN,LOG_DEL_NO
      ,LOG_DEL_YES,LOG_LIST,LOG_LOAD_BTN,LOG_NAME_DATE_TXT,LOG_SAVE_BTN
      ,LOG_SCRL,LOG_TEMP_TXT,LOG_TRACK_TXT,MAX_TEMP_BTN,MIN_TEMP_BTN
      ,OK_BTN,PG_LOG_BTN,PG_PRESS_BTN,PG_TEMP_BTN,PG_THERMAL_BTN
      ,PRESS_GAUGE,PRESS_PAUSE_BTN,PROFILE_LIST,PROFILE_SCRL,REAR_LEFT
      ,REAR_RIGHT,RES_SCRL,RES_TXT,SAVE_LOAD_BTN,SAVE_LOAD_PROG
      ,SAVE_LOAD_PROG_BOX,TEMP_GAUGE,TEMP_PAUSE_BTN,THERMAL_PAUSE_BTN
      ,THERMAL_SETT_BTN,TIME_TXT,TRACK_TEMP_BTN,TRACK_TEMP_TXT,WAKE_BTN
      ,E_ELEM_KEYPAD_NUM};
// Must use separate enum for fonts with MAX_FONT at end to use gslc_FontSet.
enum {E_BUILTIN5X8,E_DOSIS_BOLD14,E_DOSIS_BOOK8,E_FREESANS24
      ,E_FREESANS9,E_FREESANSBOLDOBLIQUE12,E_FREESANSBOLDOBLIQUE9
      ,E_NOTOSANS8,MAX_FONT};
//<Enum !End!>

// ------------------------------------------------
// Instantiate the GUI
// ------------------------------------------------

// ------------------------------------------------
// Define the maximum number of elements and pages
// ------------------------------------------------
//<ElementDefines !Start!>
#define MAX_PAGE                11

#define MAX_ELEM_PG_BASE 4 // # Elems total on page
#define MAX_ELEM_PG_BASE_RAM MAX_ELEM_PG_BASE // # Elems in RAM

#define MAX_ELEM_PG_ScreenSaver 3 // # Elems total on page
#define MAX_ELEM_PG_ScreenSaver_RAM MAX_ELEM_PG_ScreenSaver // # Elems in RAM

#define MAX_ELEM_PG_Home 13 // # Elems total on page
#define MAX_ELEM_PG_Home_RAM MAX_ELEM_PG_Home // # Elems in RAM

#define MAX_ELEM_PG_Pressure 5 // # Elems total on page
#define MAX_ELEM_PG_Pressure_RAM MAX_ELEM_PG_Pressure // # Elems in RAM

#define MAX_ELEM_PG_Temp 4 // # Elems total on page
#define MAX_ELEM_PG_Temp_RAM MAX_ELEM_PG_Temp // # Elems in RAM

#define MAX_ELEM_PG_Thermal 9 // # Elems total on page
#define MAX_ELEM_PG_Thermal_RAM MAX_ELEM_PG_Thermal // # Elems in RAM

#define MAX_ELEM_PG_Log 35 // # Elems total on page
#define MAX_ELEM_PG_Log_RAM MAX_ELEM_PG_Log // # Elems in RAM

#define MAX_ELEM_THERMAL_SETTINGS 18 // # Elems total on page
#define MAX_ELEM_THERMAL_SETTINGS_RAM MAX_ELEM_THERMAL_SETTINGS // # Elems in RAM

#define MAX_ELEM_LOG_SAVE_LOAD 13 // # Elems total on page
#define MAX_ELEM_LOG_SAVE_LOAD_RAM MAX_ELEM_LOG_SAVE_LOAD // # Elems in RAM

#define MAX_ELEM_CONFIRM_DELETE 6 // # Elems total on page
#define MAX_ELEM_CONFIRM_DELETE_RAM MAX_ELEM_CONFIRM_DELETE // # Elems in RAM
//<ElementDefines !End!>

// ------------------------------------------------
// Create element storage
// ------------------------------------------------
gslc_tsGui                      m_gui;
gslc_tsDriver                   m_drv;
gslc_tsFont                     m_asFont[MAX_FONT];
gslc_tsPage                     m_asPage[MAX_PAGE];
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
